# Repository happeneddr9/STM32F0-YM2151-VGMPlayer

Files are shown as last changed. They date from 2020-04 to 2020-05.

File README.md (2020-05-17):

HitCount (http://hits.dwyl.com/happeneddr9/happeneddr9/STM32F0-YM2151-VGMPlayer)

# STM32F0 YM2151 VGMPlayer

## Description
This project is a VGMPlayer that uses a genuine YM2151 FM synthesizer chip. This project is driven by a STM32F030 microcontroller, it's better choice than BluePill in price, and I have not written any libraries for other STM serise chips.

This project is reference from [AidanHockey5/YM2151_VGM_STM32](https://github.com/AidanHockey5/YM2151_VGM_STM32), but this is not using BluePill(STM32F103), is STM32F0 serises; using SW4STM32 with standard peripheral library.

Compared with BluePill, the STM32F0 series chip has a slower main clock, less Flash and RAM, and fewer peripherals, but that is more than enough for this project, and it is very cheap, each cost me around 0.83USD.

Using STM32F030C8 as the brain of this project, ST77xx TFT LCD for displaying VGM information, and SdFat for SD cards and file system control, most of the libraries have been optimized for STM32F0 series.

STM32F030C8 has 64kB Flash and 8kB SRAM, this project usage:
```
   text	   data	    bss	    dec	    hex
  30192	    512	   3692	  34396	   865c
```
it's very tiny, I think.
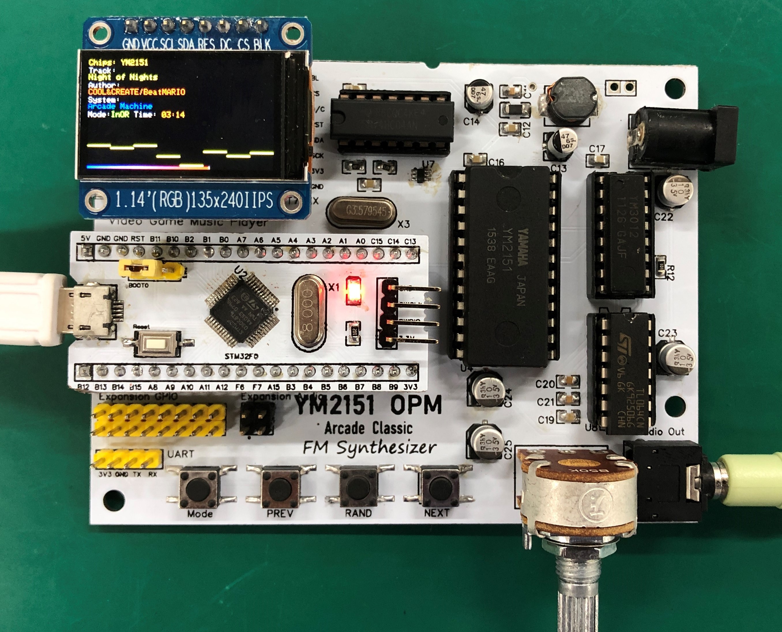
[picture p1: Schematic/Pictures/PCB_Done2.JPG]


## Requirements
- Since some files used lambda or some "modern" features, it only work with c++11 or later.
- Have STM32F0 chips or development board, potatoes isn't works well.
- Able to read sentences with awful grammar.

## Features
- SPI interface is bound with DMA, can run at full-speed (12Mbps @48MHz).
- VGMPlayer functions packed into a class.
- Have a HSV and RGB color control library, you can choose colors you like.
- ST7735 and ST7789 TFT are both supported, change it in main.cpp.

## Libraries Reference and Ported
ST77xx library source: [ST77xx Library](https://github.com/adafruit/Adafruit-ST7735-Library) by Adafruit. \
SD cards and FileSystem library source: [SdFat](https://github.com/greiman/SdFat) by greiman. \
Others ported but not used for this project. 

## Difference with original
- Different microcontroller used.
- I cannot buy the LTC6903, so I used analog multiplexer for switching two different clock.
- From 5 buttons to 4, `Mode`, `Prev`, `Rand` and `Next` buttons, have three playmode.
- Screen is full-color in here.
- Have a timebar in the screen bottom, show you total time and how much time is left.
- Timebar is RGB!
- The song will loop once if it has non-zero loop offset.
- Added a SD Cards error handler, will be call when it can't get response from SD Card, code will be stuck in here until SD Card response.
- It'll calculate how many VGM files at the beginning.

## Glitches & Problems
- *It have a unknown error in DC power jack circuit part, this error have burned my two voltage regulator and one YM2151. If you ordered PCB throught schematic doucment of this project, Please DON'T use the DC Jack for power supply, but the micro USB port on the board!*
- *In a few cases when you unplug the SD card at runtime, the "SD Cards error handler" may not work, the program will be stuck here*
- *Transcend SD Card needs to Reconnect the power before initialization, and I didn't design a circuit for SD card power control.*

## Up Next & Optimizations
- The timer callback functions isn't direct, pointer needs to jump twice(or more), which may have some performance impact, but so far, it has worked well.
- 8-bit DataBus IO (the GpioFastParallel) is too slow, but even so, it still works well at high tempo song (e.g. Night of Nights). I'll deal with it when I find a better way for bind a lot of GPIOs to a parallel port.
- Since SdFat has the `openNext()` function, `openPrev ()` may be possible.
- The next VGMPlayer project may be base on YM2608.

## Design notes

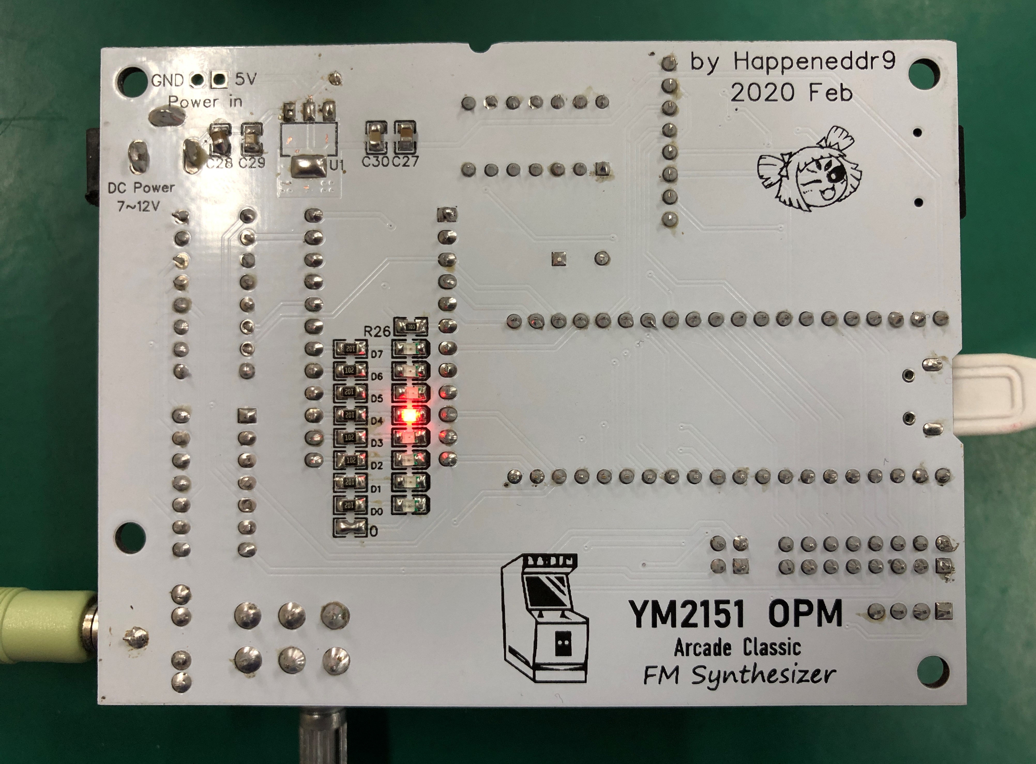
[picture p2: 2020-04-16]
Schematic/Pictures/PCB_Done_Back.JPG

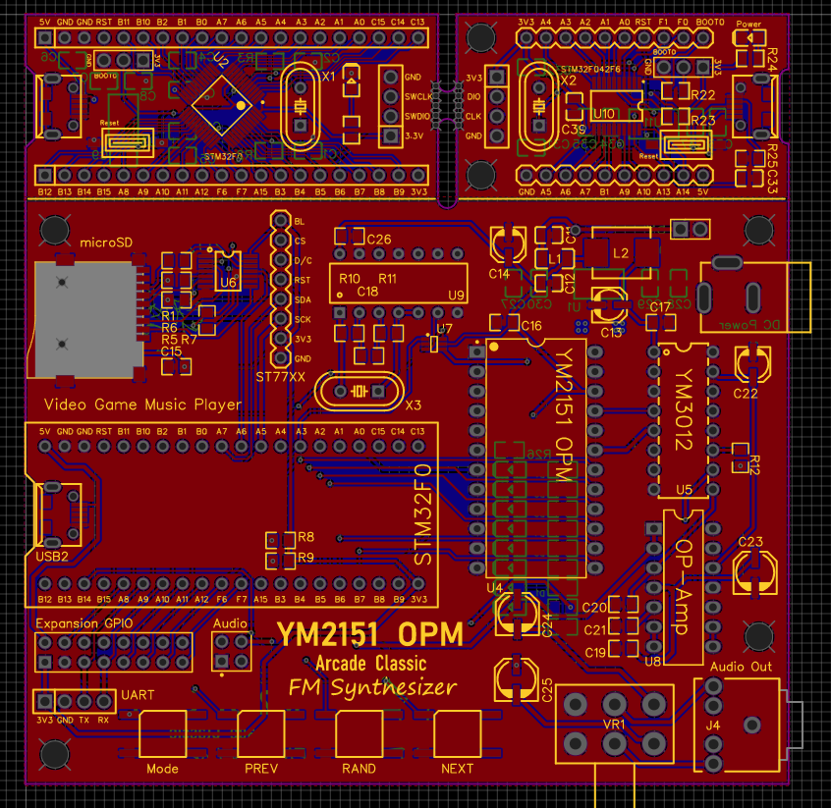
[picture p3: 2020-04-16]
Schematic/Pictures/FM_PCB.png

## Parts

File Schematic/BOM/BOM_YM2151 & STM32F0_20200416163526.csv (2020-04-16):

ID | Name | Designator | Footprint | Quantity | Manufacturer Part | Manufacturer | Supplier | Supplier Part | EasyEDA | LCSC Assembly
1 | ST-Link | H1,H6 | DIP-1X4P-2.54MM-M | 2 | 210S-1*4P L=11.6MMGold-plated black | Ckmtw | LCSC | C124378
2 | UART | H4 | DIP-1X4P-2.54MM-M | 1 | 210S-1*4P L=11.6MMGold-plated black | Ckmtw | LCSC | C124378
3 | RESET-SWI | SW2,SW1 | SWITCH-3X6X2.5_SMD | 2 | SWITCH-3x6x2.5_SMD | BBJ | EasyEDA | E71857 | E71857
4 | Expansion Audio | P3 | HDR-TH_4PIN-V-ROW2-COL2-MALE-PITCH2.54 | 1 | Double Rows2.54mm2*2pHeaders Pins | BOOMELE | LCSC | C66690
5 | YM2151 | U4 | DIP-24_24PIN-LS15.24-L31.00-W13.00-PITCH2.54 | 1 |  |  | Me
6 | F042 GPIO | H7,H8 | 210S-1X10P | 2 | 210S-1*10P L=11.6MMGold-plated black | Ckmtw | LCSC | C124372
7 | Mode | SW9 | SW4-SMD-4.5-6.0X6.0X7.5MM | 1 | ?
8 | NEXT | SW8 | SW4-SMD-4.5-6.0X6.0X7.5MM | 1 | ?
9 | RAND | SW7 | SW4-SMD-4.5-6.0X6.0X7.5MM | 1 | ?
10 | PREV | SW6 | SW4-SMD-4.5-6.0X6.0X7.5MM | 1 | ?
11 | Audio Dual POT | VR1 | POTENTIOMETER AUDIO DUAL | 1 | Audio Dual Gang Potensiometer
12 | uSD Socket | SD1 | MICRO-SD9+4P-SMD-16.1X14.5X1.85MM | 1
13 | BOOT0 | H2,H5 | HDR-TH_3P-P2.54-V | 2 | Header2.54mm 1*3P | BOOMELE | LCSC | C49257
14 | Bead | L1 | L1206 | 1 | 2512066017Y1 | Fair Rite
15 | 0.1u | C7,C10,C12,C6,C29,C30,C33,C34,C37 | C0805 | 9
16 | 10u | C8,C9,C28,C27,C35,C36 | C0805 | 6
17 | 10n | C11 | C0805 | 1
18 | 22p | C2,C1,C31,C32 | C0805 | 4
19 | 0.1uF | C3,C4,C5,C39 | C0805 | 4
20 | STM32F030C8 BluePill | BOARD1 | STM32F030CX_BLUEPILL-40-2.54MM | 1 |  |  | Me
21 | DC Power | P2 | DC005-2.5MM | 1 | Three-pin power interface DC005 2.5MMsocket Bagged RHOS | ReliaPro | LCSC | undefined
22 | 47u | C14,C13 | CAP-D4.0XH5.5 | 2
23 | 10u | C22 | CAP-D4.0XH5.5 | 1
24 | AUDIO-JACKPTH | J4 | AUDIO-JACK | 1
25 | 220u | C23 | CAP-D5.0XH5.5 | 1
26 | 10u | C24,C25 | CAP-D5.0XH5.5 | 2
27 | Power LED | LED1,LED10 | LED-0805 | 2 | 17-21SURC/S530-A2/TR8 | EVERLIGHT | LCSC | C131244
28 | Data LED | LED2,LED3,LED4,LED5,LED9,LED8,LED7,LED6 | LED-0805 | 8 | 17-21SURC/S530-A2/TR8 | EVERLIGHT | LCSC | C131244
29 | 10k | R3,R2,R22,R23 | R0805 | 4
30 | 1k | R4,R24 | R0805 | 2
31 | STM32 IO | J2,J1 | HDR-TH_20PIN-V-MALE-PITCH2.54 | 2 | 2.54mm 1*20PHeader | BOOMELE | LCSC | C50981
32 | 74LVC125APW,118 | U6 | TSSOP-14 | 1 | 74LVC125APW,118 | Nexperia | LCSC | C6059
33 | 33uH | L2 | IND-SMD_L7.5-W6.6 | 1 | GCDA0630-330MC | GLE | LCSC | C439280
34 | 0.1u | C15,C16,C17,C18,C19,C26 | 0805' | 6
35 | 3.3n | C20,C21 | 0805' | 2
36 | LD1117S18CTR | U3,U1,U11 | SOT-223 | 3
37 | Analog MUX | U7 | SC-70-6(SOT-363) | 1 | SN74LVC1G3157DCKR | TI | LCSC | C38663 |  | Yes
38 | ST77XX | H3 | 210S-1X8P | 1 | 210S-1*8P L=11.6MMGold-plated black | Ckmtw | LCSC | C124381
39 | Power in | H9 | HDR-2X1/2.54 | 1 | 826629-2 | TE Connectivity | LCSC | C86471
40 | Expansion GPIO | P1 | HDR-8X2/2.54 | 1 | Double row straight 2*8Headers Pins 2.54mm | BOOMELE | LCSC | C68234
41 | 74HC04 | U9 | DIP14 | 1
42 | 8MHz | X1,X2 | HC-49US_L11.5-W4.5-P4.88 | 2 | X49SD12MSD2SC | YXC | LCSC | C16369
43 | 3.579545MHz | X3 | HC-49US_L11.5-W4.5-P4.88 | 1 | X49SD12MSD2SC | YXC | LCSC | C16369
44 | MicroUSB | USB1,USB2,USB3 | MICRO-USB-1 | 3 | micro USBFemale | ValuePro | LCSC | C10418
45 | STM32F042F6P6 | U10 | TSSOP-20 | 1 | STM32F042F6P6 | STMicroelectronics | LCSC | C81000
46 | YM3012 | U5 | DIP-16_L20.0-W6.4-P2.54-LS7.6-BL | 1 |  |  | Me
47 | 3.3k | R1,R5,R6,R7 | 0805' | 4
48 | 4.7k | R8,R9 | 0805' | 2
49 | 470 | R10,R11 | 0805' | 2
50 | 100 | R12 | 0805' | 1
51 | 1k | R13,R14,R15,R16,R17,R18,R19,R20 | 0805' | 8
52 | 0 | R21 | 0805' | 1
53 | 100k | R25 | 0805' | 1
54 | 10k | R26 | 0805' | 1
55 | STM32F030C8T6 | U2 | STM-LQFP48 | 1
56 | TL064 | U8 | DIP-14_L20.0-W7.6-P2.54-LS7.6-BL | 1

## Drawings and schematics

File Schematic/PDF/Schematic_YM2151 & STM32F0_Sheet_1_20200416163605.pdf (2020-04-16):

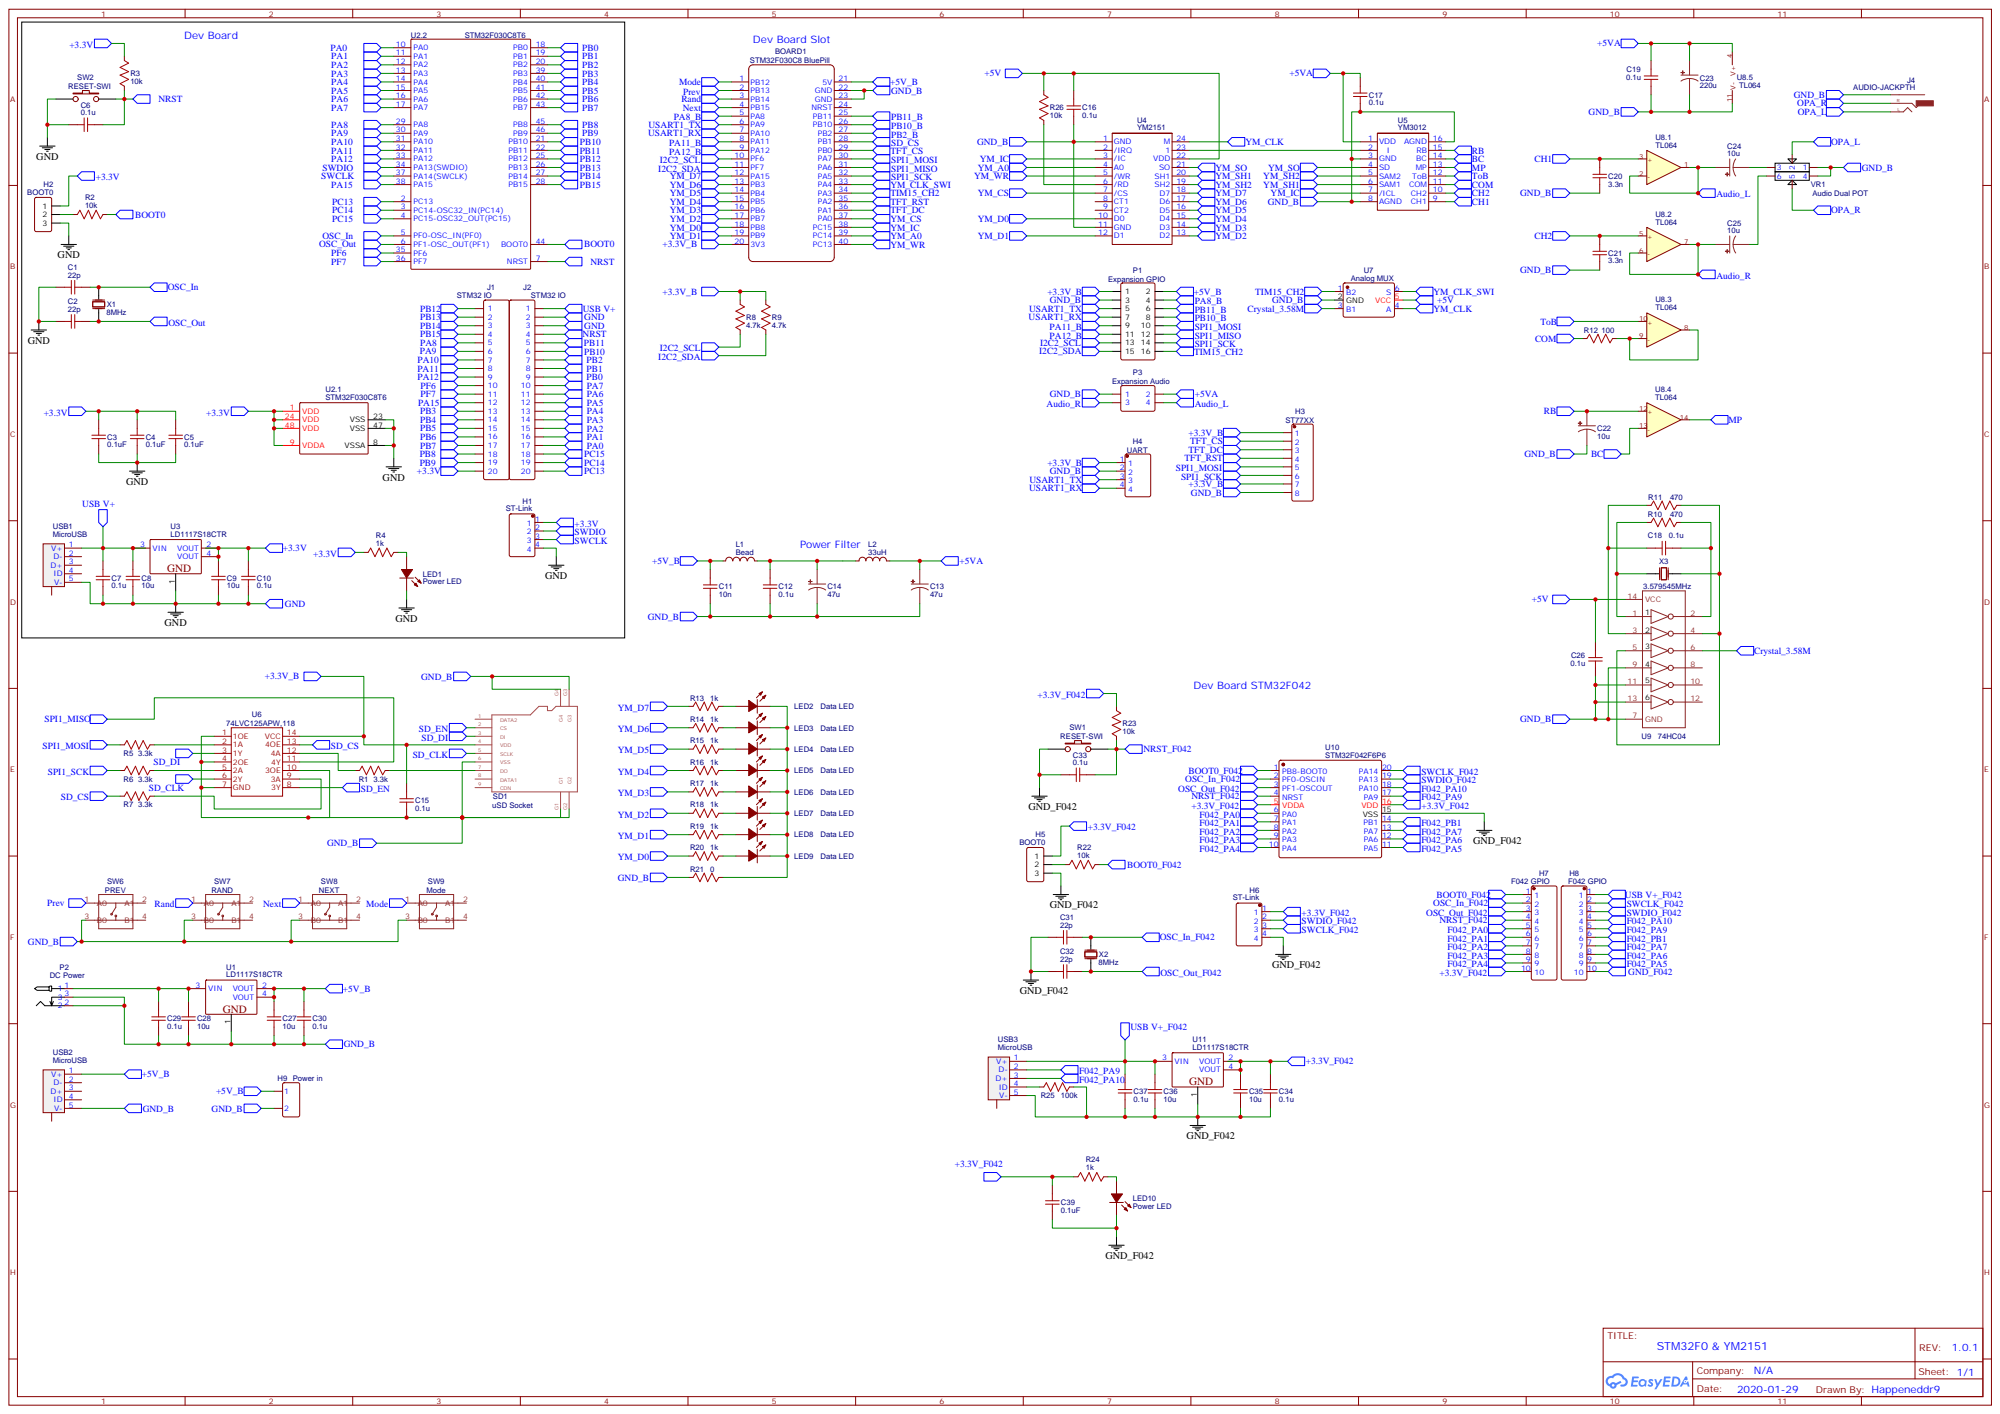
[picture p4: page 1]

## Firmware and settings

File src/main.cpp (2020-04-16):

/**			<! Coding with UTF-8 >
 *   Date      :   2019/11/09     YYYY-MM-DD
 *   Author    :   Happeneddr9
 *   Font use  :   Consolas with YaHei 雅黑體
 *
 *   @brief:	YM2151 VGM Player code
 *
 *		UTF-8 TextTest: マフェット
 */

/**
 *	系統參數請到 Basic.h 或 main.h 處修改
 *	System parameter defined in header "Basic.h" or "main.h"
 */
#include "Arduino/Basic.h"         		// use delay()  millis()
#include "HardwareUart/HWSerial0.h"     // use Serial  硬體UART串列阜

#include "TIMER/TIMER3.hpp"				// I implemented only timer3, others you need to call IRQHandler.

#include "Sound/VGM_Player.h"			// VGM Player Class Object

// <!# Warning!: PA13 and PA14 using for the ST-LINK, so avoid to use them for GPIO !>

Spi_dma Spi(SPI1, SPI1_IRQn);

extern "C" {	// IRQ Handler
	// function name called DMA1_Channel2_3_IRQHandler in not F030 devices.
	void DMA1_CH2_3_IRQHandler(void) {
		Spi.IRQ_handler();
	}
}

inline void tick();


SdFat SD(PB1, Spi);
SdFile file;

// the lowest is D0, 8-bits data bus.
// auto DataBus = make_GpioFastParallel(PB8, PB9, PB7, PB6, PB5, PB4, PB3, PA15);
YM2151::DataBusType DataBus(PB8, PB9, PB7, PB6, PB5, PB4, PB3, PA15);

// YM2151			Bus		CS	  RD    WR    A0   IRQ    IC
const YM2151 opm(DataBus, PA0, NoPin, PC13, PC14, NoPin, PC15);
// RD and IRQ pin not used.

//ST7735 tft(Spi, 128, 160, PA3, PA2, PA1);
ST7789 tft(Spi, 135, 240, PB0, PA1, PA2);
const GpioPin buttons[4] = {PB15, PB14, PB13, PB12};					// control buttons array.
VGM_Player player(SD, file, Timer3, opm, tft, buttons, Serial, PA4);

// Timer for clock generator.
const Timer Timer15(TIM::Timer15, TIM15_IRQn);

int main(void) {
	SysTickInit(1000);     // 系統時鐘頻率 預設1kHz 此設定會影響到 delay() millis() std::chrono
	Serial.begin(38400, Usart1::PinMap_TXRX::DefaultMap);

	Spi.begin();
	tft.init(135, 240);		// ST7789
	//tft.begin();			// ST7735

	tft.setTextSize(1);
	tft.setTextColor(Pixel::Green);
	tft.setRotation(3);					// Rotation to suit for your screen.
	tft.fillScreen(Pixel::Black);
	tft.setCursor(0, 0);

	// Generate a 4MHz in PA3, for YM2151
	Timer15.GenerateClock(4000000);
	//Timer15.Clock_Config(23, 1);
	Timer15.PWM_Config(PA3, PWM::Channel2, GpioAF::AF0);
	Timer15.PWM_Compare_CH2(1);
	Timer15.start();

	player.begin();
	player.run(tick);



	for (;;) {

	}
}

inline void tick(void) {
	player.tick();
}

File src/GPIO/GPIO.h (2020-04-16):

/*
 * GPIO.h
 *
 *  Created on: 2019年11月11日
 *      Author: happe
 */

#ifndef GPIO_GPIO_H_
#define GPIO_GPIO_H_

#include "main.h"
#include "GPIO_namespace.h"
#include <array>
#include <initializer_list>
#include <type_traits>

enum pinMode_Status
	: uint8_t {
		INPUT = 0x00,
	OUTPUT = 0x01,
	AFunction = 0x02,
	ANALOG = 0x03,
	OUTPUT_PP = OUTPUT,
	OUTPUT_OD = 0x05,
	INPUT_PULLUP = 0x10,
	INPUT_PULLDOWN = 0x20
};

constexpr GPIO_TypeDef * const GPIO_Port_Defines[] = {
GPIOA,
GPIOB,
GPIOC,
GPIOD,
#if !defined(STM32F051)
		GPIOE,
#else
		GPIOA,
#endif
		GPIOF };

constexpr const uint32_t GPIO_RCC_Defines[] = {
RCC_AHBPeriph_GPIOA,
RCC_AHBPeriph_GPIOB,
RCC_AHBPeriph_GPIOC,
RCC_AHBPeriph_GPIOD,
#if !defined(STM32F051)
		RCC_AHBPeriph_GPIOE,
#else
		0x00,
#endif
		RCC_AHBPeriph_GPIOF };

// get the GPIO Port Peripheral Address
// and also setup the RCC Clock
// if none, return GPIOA. TODO: looking for a better way
inline constexpr GPIO_TypeDef* getPortBase(Port port) {
	/*if (static_cast<uint8_t>(port) > GpioPin::last_port) {
	 return GPIO_Port_Defines[0];
	 } else {
	 uint8_t port_n = static_cast<uint8_t>(port);
	 //RCC->AHBENR |= GPIO_RCC_Defines[0] << port_n;
	 return GPIO_Port_Defines[port_n];
	 }*/

	uint8_t port_n =
			(static_cast<uint8_t>(port) > GpioPin::last_port) ?
					0 : static_cast<uint8_t>(port);

	return GPIO_Port_Defines[port_n];

	/*switch (port) {
	 case Port::A:
	 RCC->AHBENR |= RCC_AHBPeriph_GPIOA;
	 return GPIOA;
	 break;
	 case Port::B:
	 RCC->AHBENR |= RCC_AHBPeriph_GPIOB;
	 return GPIOB;
	 break;
	 case Port::C:
	 RCC->AHBENR |= RCC_AHBPeriph_GPIOC;
	 return GPIOC;
	 break;
	 case Port::D:
	 RCC->AHBENR |= RCC_AHBPeriph_GPIOD;
	 return GPIOD;
	 break;
	 #if !defined(STM32F051)
	 case Port::E:
	 RCC->AHBENR |= RCC_AHBPeriph_GPIOE;
	 return GPIOE;
	 break;
	 #endif
	 case Port::F:
	 RCC->AHBENR |= RCC_AHBPeriph_GPIOF;
	 return GPIOF;
	 break;
	 default:
	 break;
	 }
	 return GPIOA;*/
}

///**
// * @brief : common Gpio Pin
// * @param : GpioPin or Port number + pin number
// *
// *
// */
//class Gpio {
//	public:
//		enum types : uint8_t {
//			NotGpio = 255,
//		};
//		// using GpioPin to initialize
//		constexpr Gpio(GpioPin GP = NoPin)
//				: mPort(getPortBase(GP.port)), mPin(GP.pin) {
//			RCC->AHBENR |= RCC_AHBPeriph_GPIOA << static_cast<uint8_t>(GP.port);
//		}
//
//		// using Port number and pin number to initialize
//		constexpr Gpio(Port port, uint8_t pin)
//				: Gpio(GpioPin{port, pin}) {
//
//		}
//
//		//  default none
//		~Gpio() = default;
//
//		/**
//		 *  @brief : Higher Abstract Gpio Mode initialize
//		 *  @param[in]: pinMode_Status enum
//		 *  @param[in]:	Gpio Speed Setting, 2MHz, 25MHz or 50MHz		# default use Highest Speed
//		 */
//		void begin(pinMode_Status mode_in, GpioSpeed GpioSP = GpioSpeed::s50MHz) {
//			uint8_t modex = static_cast<uint8_t>(mode_in);
//			GpioMode mode = static_cast<GpioMode>(modex & 0x03);
//			GpioOutType GpioOT = static_cast<GpioOutType>((modex & 0x0C) >> 2);
//			GpioPuPd GpioPP = static_cast<GpioPuPd>((modex & 0x30) >> 4);
//
//			init(mode, GpioOT, GpioSP, GpioPP);
//		}
//
//		/**
//		 *  @brief : Gpio Mode initialize
//		 *  @param[in]:	Input Pin, Output Pin, Analog Pin or AF Pin		# default use input
//		 *  @param[in]:	Push-Pull or Open Drain (for Output)			# default use Push-Pull
//		 *  @param[in]:	Gpio Speed Setting, 2MHz, 25MHz or 50MHz		# default use Highest Speed
//		 *  @param[in]: Gpio's Pull-up or Pull-down						# default is floatting
//		 */
//		void init(GpioMode mode = GpioMode::In, GpioOutType GpioOutType = GpioOutType::PP,
//				GpioSpeed GpioSpeed = GpioSpeed::s50MHz, GpioPuPd GpioPuPd = GpioPuPd::NoPull) const {
//			if (mPort != nullptr) {
//				uint8_t dmPin = mPin * 2;
//				mPort->MODER |= static_cast<uint32_t>(mode) << dmPin;
//				mPort->OSPEEDR |= static_cast<uint32_t>(GpioSpeed) << dmPin;
//				mPort->OTYPER |= static_cast<uint16_t>(GpioOutType) << mPin;
//				mPort->PUPDR |= static_cast<uint32_t>(GpioPuPd) << dmPin;
//			}
//		}
//
//		void setAF(GpioAF af) const {
//			const uint32_t MskOft = static_cast<uint32_t>(mPin & static_cast<uint32_t>(0x07)) * 4;
//			const uint32_t AfMask = ~(static_cast<uint32_t>(0xf) << MskOft);
//			const uint32_t AfValue = (static_cast<uint32_t>(af) << MskOft);
//			const uint32_t AfrIdx = mPin >> 3;
//
//			mPort->AFR[AfrIdx] &= AfMask;
//			mPort->AFR[AfrIdx] |= AfValue;
//		}
//
//		inline GPIO_TypeDef* getGPIOPort(void) const {
//			return mPort;
//		}
//
//		inline uint8_t getPinNum(void) const {
//			return mPin;
//		}
//
//		inline uint16_t getPinNum16(void) const {
//			return 1 << mPin;
//		}
//
//		inline void setState(bool state) const {
//			state ? setHigh() : setLow();
//		}
//
//		finline void setHigh() const {
//			mPort->BSRR = 1 << mPin;
//		}
//
//		finline void setLow() const {
//			mPort->BRR = 1 << mPin;
//		}
//
//		finline bool read() const {
//			return mPort->IDR & 1 << mPin;
//		}
//
//		finline void toggle() const {
//			mPort->ODR ^= 1 << mPin;
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

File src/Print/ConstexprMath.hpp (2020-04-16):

/**
 * @Name    : ConstexprMath.hpp
 * @Date    : 2019年11月21日 下午10:57:46
 * @Author  : happe
 * @brief   :
 */

#ifndef PRINT_CONSTEXPRMATH_HPP_
#define PRINT_CONSTEXPRMATH_HPP_

#include "main.h"
#include "Basic.h"
#include <cmath>
#include <type_traits>
#include <limits>

namespace Mathexpr {
	template <typename T, size_t len>
	struct ArrayStruct {
			T val[len];
			T operator [](size_t index) const {
				return val[index];
			}
	};

	// 1/4 sine table
	template <typename T, size_t len>
	constexpr ArrayStruct<T, len> Sine_Quarter_generator(int range) {
		ArrayStruct<T, len> tmp { };
		long double angle { };
		constexpr auto T_max = std::numeric_limits<T>::max();
		constexpr auto T_sign = std::is_signed<T>::value;

		if (range > T_max) {
			range = T_max;
		}

		for (size_t i = 0; i < len; i++) {
			angle = i * PI_base<long double> / static_cast<long double>(len * 2.0);
			if (T_sign) {
				tmp.val[i] = (range * std::sin(angle));
			} else {
				tmp.val[i] = ((T_max / 2.0) + (range * __builtin_sin(angle)));
			}
		}
		return tmp;
	}

	// 1/2 sine table
	template <typename T, size_t len>
	constexpr ArrayStruct<T, len> Sine_Half_generator(int range) {
		ArrayStruct<T, len> tmp { };
		long double angle { };
		constexpr auto T_max = std::numeric_limits<T>::max();
		constexpr auto T_sign = std::is_signed<T>::value;

		if (range > T_max) {
			range = T_max;
		}

		for (size_t i = 0; i < len; i++) {
			angle = i * PI_base<long double> / static_cast<long double>(len);
			if (T_sign) {
				tmp.val[i] = (range * std::sin(angle));
			} else {
				tmp.val[i] = ((T_max / 2.0) + (range * std::sin(angle)));
			}
		}
		return tmp;
	}

	// Full sine table
	template <typename T, size_t len>
	constexpr ArrayStruct<T, len> Sine_Full_generator(int range, bool start_form_zero = true) {
		ArrayStruct<T, len> tmp { };
		long double angle = 0;
		constexpr auto T_max = std::numeric_limits<T>::max();
		constexpr auto T_sign = std::is_signed<T>::value;
		int T_minus = start_form_zero ? ((T_max / 2.0) - range) : 0;

		constexpr long double len_base = (len / 2.0L);

		for (size_t i = 0; i < len; i++) {
			angle = i * PI_base<long double> / len_base;
			if (T_sign) {
				tmp.val[i] = (range * std::sin(angle));
			} else {
				tmp.val[i] = ((T_max / 2.0) + (range * std::sin(angle))) - T_minus;
			}
		}
		return tmp;
	}

}

#endif /* PRINT_CONSTEXPRMATH_HPP_ */

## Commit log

2020-04-16 Update code files
    [YM2151_VGM_fin Run.cfg]
2020-04-16 added schematic files
    [BOM_YM2151 & STM32F0_20200416163526.csv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]
